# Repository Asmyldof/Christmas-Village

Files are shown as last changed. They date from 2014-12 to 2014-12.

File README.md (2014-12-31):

Christmas-Village
=================
A two cheap microcontroller project to control which of ten channels is on or off based on a true-random generator (with guaranteed no bias), while also controlling the general brightness either manually or from a light sensor.
The remainder of this ReadMe will be written as a chronological logbook, to show the speed at which the development was done.

How a missing connector inspired me to make a present in stead of buying one:
=================

Early December 2013:
-----
I glue some LED strips into the crockery Christmas Village houses my parents bought and supplied father with some pre-fab connectors and cables. That year the houses were lit at a fraction of the cost of high-watage incandescent bulbs from the supplier. (Where the LEDstrip uses less than 1/10th the power).

Early January 2014:
-----
The houses get packed into wraps and boxes.

December 19th 2014:
-----
Father WhatsApps to ask about the connector set-up, because the old one seems to have fallen out of the package at some point. We call and agree that I will get a new connector to go from one single power supply to ten houses the next week, for the main holidays (as they were busy upto Dec 22nd)

December 20th 2014:
-----
I start designing a PCB to control the houses with the shortest-path-available method, still considering reusability, and thus splitting the dimmer and the 10 channel on/off controller into two separate, relatively cheap Atmel AVRs.
The plan:
* First and foremost: Use only items from my direct stock (My stock is large, very large even, but not limitless), so it can be built the same weekend.
* Get an ATTiny10 to do the dimming and keeping an eye on the light/dark situation
* Get an ATTiny4313 to control the channels on/off, including a true-random generator without bias (more on this later)
* Add a FM noise source for very-high-speed random generation (for future plans) (see below why that's not in there anymore)

December 21st 2014 (late night):
-----
With the hardware fully designed it's time to start the etching

December 22nd 2014 (afternoon):
-----
With the hardware fully built it's time to test the noise generation from the FM antenna. The FM antenna proves to be unreliable and insensitive in the small box that has been chosen, so a lower-frequency noise source is taken: The good old Zener Diode.

December 22nd 2014 (early evening):
-----
The ATTiny10 software is ready for testing, but a paid projct takes temporary precedence.

December 22nd 2014 (late evening):
-----
The ATTiny10 is working and installed, time to go bring what is done as a present to the parental home and continue programming there later.

December 22nd/23rd 2014 (midnight and later):
-----
Development of the random control is well underway (all chips were already mounted before ATTiny10 testing started).

December 23rd 2014 (approx 5:30 AM):
-----
Random control of the houses works, time to decouple the programmer and go to bed, allowing the random behaviour as a surprise for the folks that'll wake up soon.

December 23rd (5:30 AM) through december 26th:
-----
Break (the houses are automatically dimmed by the sensor and the light sensor sucessfully influences the number of houses on - more on during the day time than during the night time - and the random behaviour works, that was the target for christmas.
(However, some work had already been done for other functionality, including patterns and EEPROM re-configurable settings, which should later be read/write-able through the serial interface (quick after thought in the hardware design).

December 27th 2014:
-----
Continuation of the development: Adding Serial interface, interleaved with shopping, cleaning and such.
(Note, however, that the hardware is not available at this point, so all code is written and tested on paper only, undoubtedly leaving bugs to be discovered when the hardware is back again for a while.)

December 28th 2014 (2:30 AM):
-----
Serial command set almost completely implemented, before the remaining command get implemented the default eeprom_ routines from AVR-GCC need to be switched over to interrupt driven and flag-bocked, or some routine splitting needs to be done to get the blocking eeprom read/writes in the non-interrupt space inside main(). Else the "ReadPattern" and "WritePattern" commands will hold up too many interrupts.

December 28th 2014 (14:00 to 16:30):
-----
A small window of hardware testing, allowing debugging of the USART code and changing some variables into GPIOR, to decrease code size. Basic USART system working, not all commands fully tested yet.

December 30th, 31st 2014 and January 1st, 2nd and 3rd 2015:
-----
More debugging to be done, before the hardware leaves, small sessions in between other activities, it's a busy week after all. Plan is to complete the USART (excepting GoToBootloader)and EEPROM interfaces and hopefully make the pattern system work completely. Once that is all completed andthere is still room enough for a two or three page fixed bootloader, at least in the 4313 setup, that will be added later (weekends during January 2015, or a little later)

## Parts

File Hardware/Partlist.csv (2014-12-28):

Partlist |  | Christmas Village Project
Part | Value | Package | Library | Position (mil) | Orientation
C1 | 2u2 | CAP-1206 | ipc-7351-capacitor | (1880 1340) | R90
C2 | 2u2 | CAP-1206 | ipc-7351-capacitor | (1880 1150) | R270
C3 | 100n | CAP-0603 | ipc-7351-capacitor | (2920 700) | R0
C4 | 100n | CAP-0603 | ipc-7351-capacitor | (3260 1390) | R90
C5 | 100n | CAP-0603 | ipc-7351-capacitor | (2260 900) | R180
C6 |  | CAP-0603 | ipc-7351-capacitor | (2340 1250) | R0
C7 |  | CAP-0603 | ipc-7351-capacitor | (2540 710) | R180
C8 | 1u | CAP-1206 | ipc-7351-capacitor | (2560 515) | R0
C9 | 1u | CAP-1206 | ipc-7351-capacitor | (2580 295) | R0
C10 | 100n | CAP-0603 | ipc-7351-capacitor | (3110 90) | R0
C11 | 100n | CAP-0603 | ipc-7351-capacitor | (1920 970) | R270
C12 | 560pF | CAP-0603 | ipc-7351-capacitor | (1910 610) | R90
C13 | 56nF | CAP-0603 | ipc-7351-capacitor | (2130 1020) | R90
CN1 | MJ-180SMT | MJ-180SMT | con-Multicomp | (80 1330) | R0
CN2-PROG | JST-6PSPI-SIDE-S6B | 6P-H | avr-6 | (3150 1420) | R180
CN3-SERIAL | JST-4PSIDE-S4B | 4P-H | Connector-2mm | (2590 1420) | R180
CN5-LEDSTRIPS | HDR_2X10_SIDE-MOUNT | 20PIN-10TOP-10BOT | con-SideHeader | (3620 1440) | R270
D1 | BP104-SMD-REV | BR104SMDREV | Vishay | (1660 380) | R270
D2 |  | MINIMELF | diode | (2080 1390) | R0
D3 | 9V1 | SOT23 | diode | (2380 390) | R180
IC1 | UA78M05DCY | SOT223 | linear | (2110 1210) | R270
IC2 | LM358D | SO08 | linear4 | (2050 800) | R0
IC3 | LM358D | SO08 | linear4 | (2870 525) | R270
IC4 | LM358D | SO08 | linear4 | (2870 205) | R90
IC5 | ATTINY-4/5/9/10 | SOT23-6 | avr-6 | (2180 1060) | R270
IC6 | TINY2313/4313 | SO20 | avr-6 | (2960 1090) | R270
POT1 |  | HDR-1x3 | con-hdrs40 | (2040 460) | R0
Q1 | Si2309CD | SOT95P280X135-3N | ipc-7351-transistor | (3590 1540) | R0
Q2 | NX7002AKW | SOT323R | ZeroCross Project | (3310 1560) | R270
Q3 | NX7002AKW | SOT323R | ZeroCross Project | (3470 1420) | R270
Q4 | NX7002AKW | SOT323R | ZeroCross Project | (3470 1330) | R270
Q5 | NX7002AKW | SOT323R | ZeroCross Project | (3470 1240) | R270
Q6 | NX7002AKW | SOT323R | ZeroCross Project | (3470 1140) | R270
Q7 | NX7002AKW | SOT323R | ZeroCross Project | (3470 1040) | R270
Q8 | NX7002AKW | SOT323R | ZeroCross Project | (3470 940) | R270
Q9 | NX7002AKW | SOT323R | ZeroCross Project | (3470 840) | R270
Q10 | NX7002AKW | SOT323R | ZeroCross Project | (3470 740) | R270
Q11 | NX7002AKW | SOT323R | ZeroCross Project | (3470 640) | R270
Q12 | NX7002AKW | SOT323R | ZeroCross Project | (3470 540) | R270
R1 | 10M | RES-0603 | ipc-7351-resistor | (1995 630) | R180
R2 | 10k | RES-0603 | ipc-7351-resistor | (1900 810) | R90
R3 | 100k | RES-0603 | ipc-7351-resistor | (2040 1010) | R180
R4 | 10k | RES-0603 | ipc-7351-resistor | (3490 1540) | R90
R5 | 10k | RES-0603 | ipc-7351-resistor | (3410 1580) | R0
R6 | 10k | RES-0603 | ipc-7351-resistor | (2680 475) | R270
R7 | 99k | RES-0603 | ipc-7351-resistor | (2660 185) | R270
R8 | 1k | RES-0603 | ipc-7351-resistor | (2640 395) | R180
R9 | 500k | RES-0603 | ipc-7351-resistor | (2730 335) | R180
R10 | 10k | RES-0603 | ipc-7351-resistor | (3080 170) | R90
R11 | 10k | RES-0603 | ipc-7351-resistor | (3080 290) | R90
R12 | 1M | RES-0603 | ipc-7351-resistor | (2380 210) | R90
SW1 | POWER | HDR-1x3 | con-hdrs40 | (2040 1550) | R0
SW2 | NIGHT-MODE | HDR-1x3 | con-hdrs40 | (2040 210) | R0
X1 | 7.3728MHz | SM49 | crystal | (2440 980) | R90

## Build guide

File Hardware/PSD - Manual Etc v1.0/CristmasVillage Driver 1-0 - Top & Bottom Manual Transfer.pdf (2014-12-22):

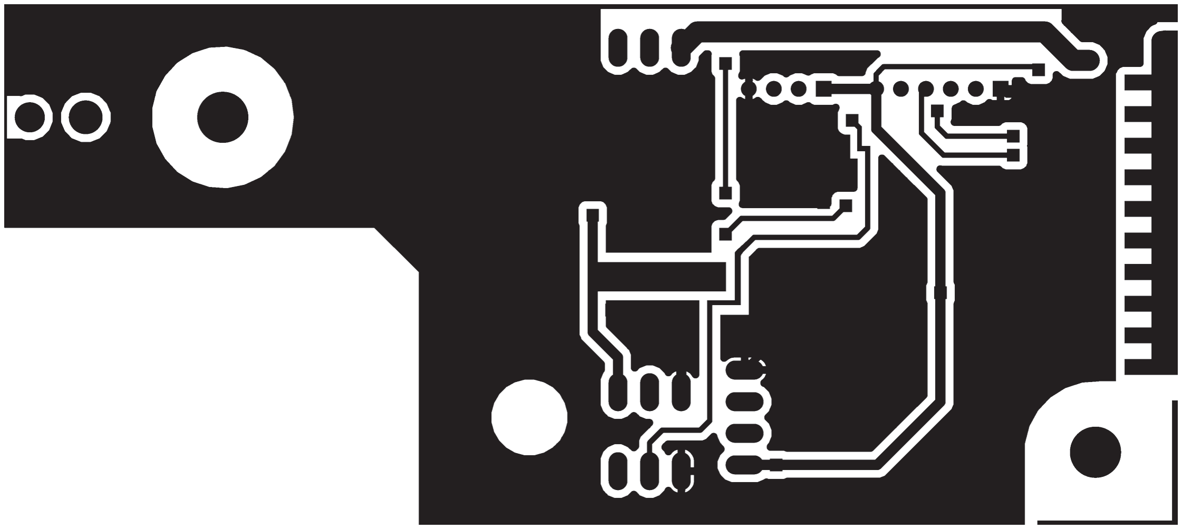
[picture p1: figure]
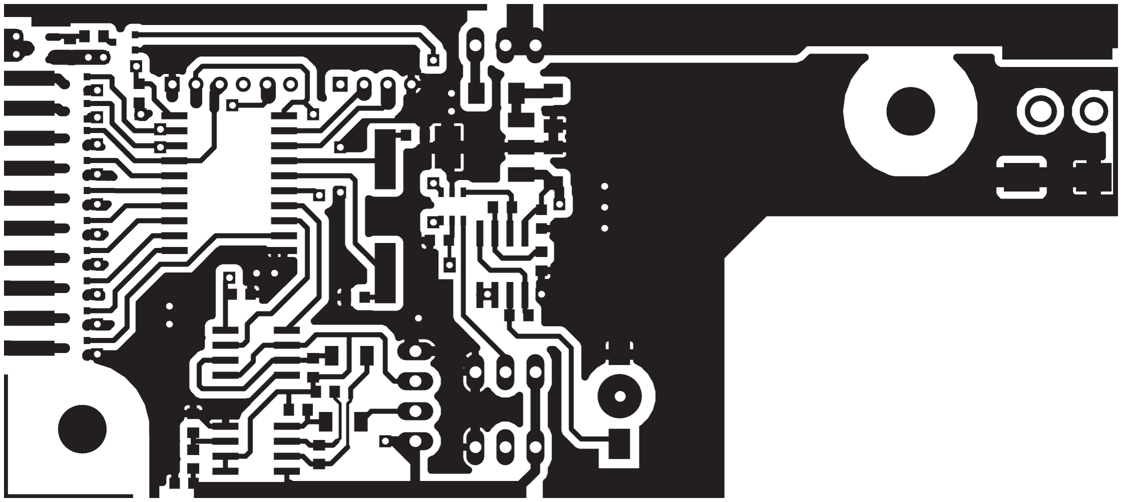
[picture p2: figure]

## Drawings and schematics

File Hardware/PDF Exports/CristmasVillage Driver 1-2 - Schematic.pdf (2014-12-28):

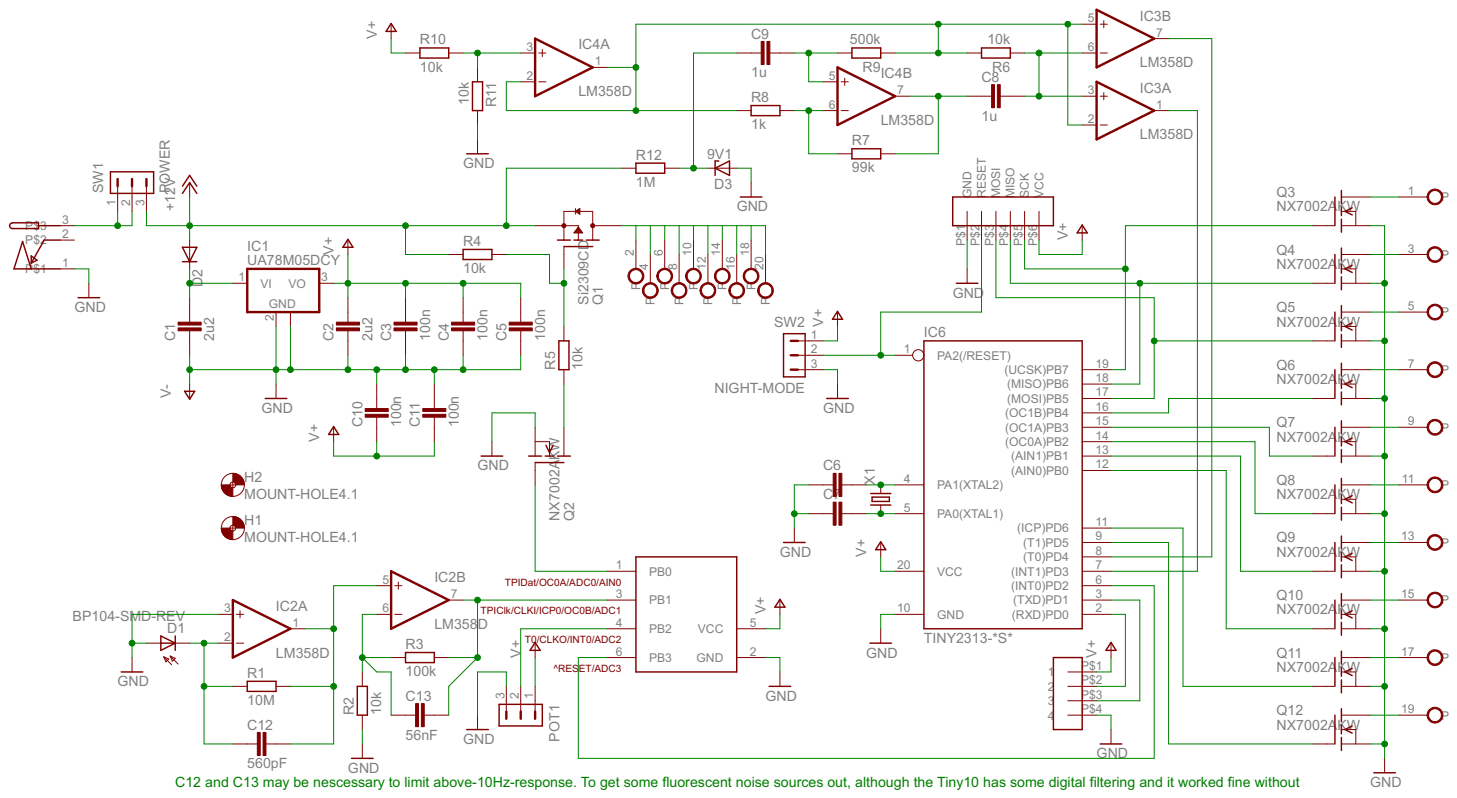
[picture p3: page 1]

14
13
12

TPIDat/OC0A/ADC0/AIN0 TPIClk/CLKI/ICP0/OC0B/ADC1 T0/CLKO/INT0/ADC2

^RESET/ADC3 C12 and C13 may be nescessary to limit above-10Hz-response. To get some fluorescent noise sources out, although the Tiny10 has some digital filtering and it worked fine without

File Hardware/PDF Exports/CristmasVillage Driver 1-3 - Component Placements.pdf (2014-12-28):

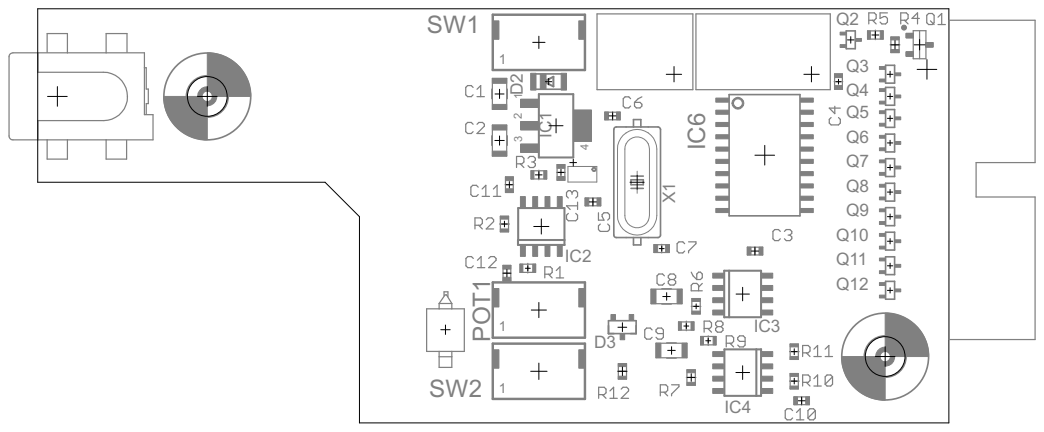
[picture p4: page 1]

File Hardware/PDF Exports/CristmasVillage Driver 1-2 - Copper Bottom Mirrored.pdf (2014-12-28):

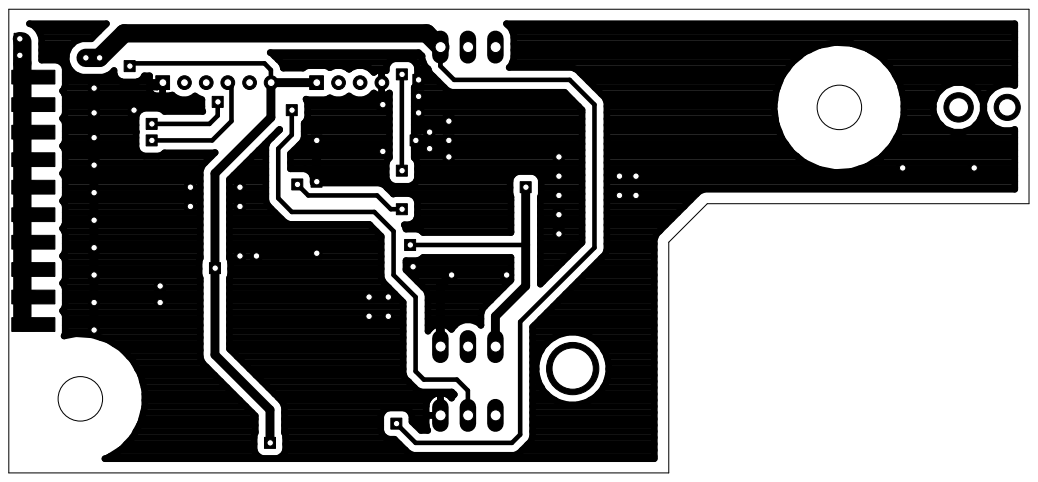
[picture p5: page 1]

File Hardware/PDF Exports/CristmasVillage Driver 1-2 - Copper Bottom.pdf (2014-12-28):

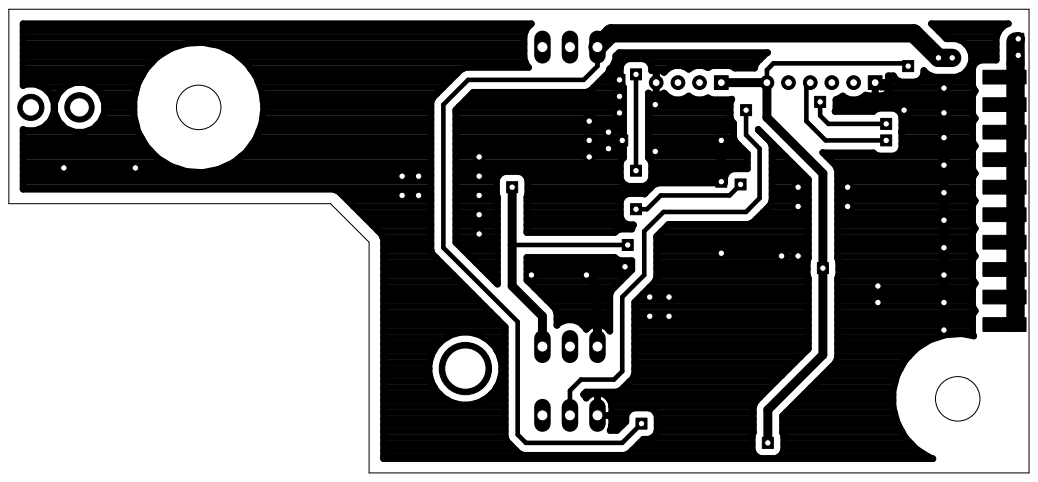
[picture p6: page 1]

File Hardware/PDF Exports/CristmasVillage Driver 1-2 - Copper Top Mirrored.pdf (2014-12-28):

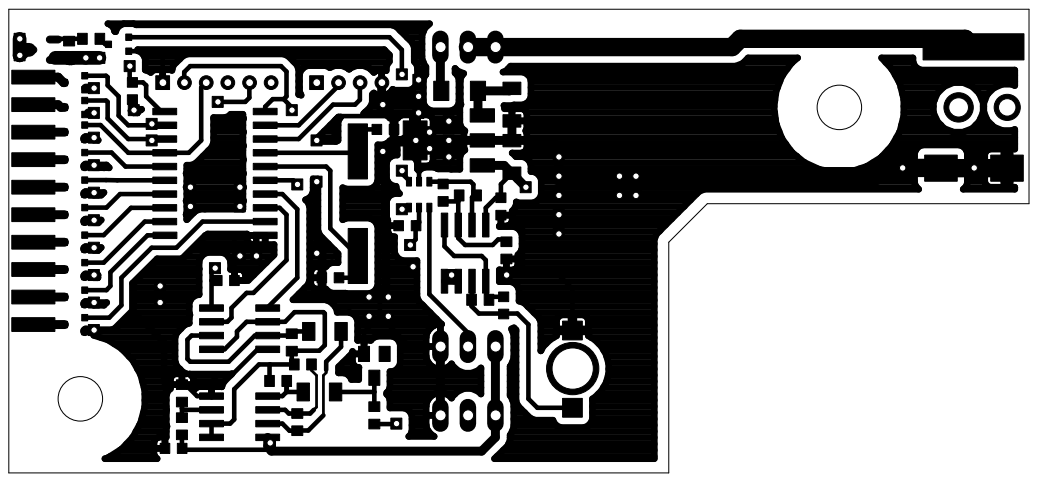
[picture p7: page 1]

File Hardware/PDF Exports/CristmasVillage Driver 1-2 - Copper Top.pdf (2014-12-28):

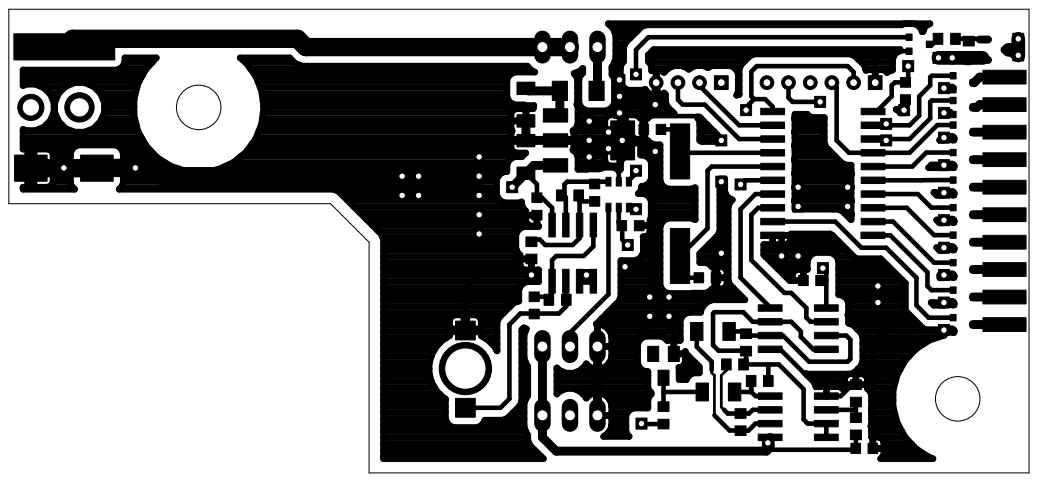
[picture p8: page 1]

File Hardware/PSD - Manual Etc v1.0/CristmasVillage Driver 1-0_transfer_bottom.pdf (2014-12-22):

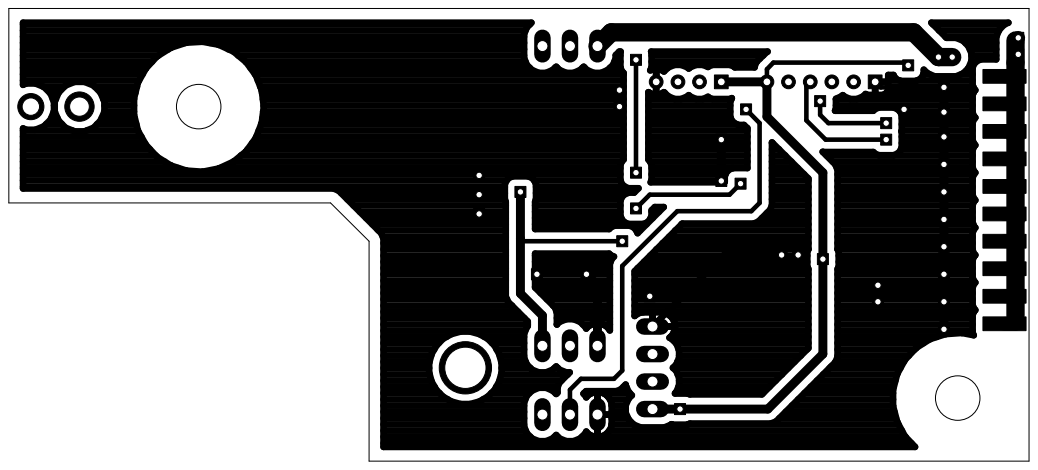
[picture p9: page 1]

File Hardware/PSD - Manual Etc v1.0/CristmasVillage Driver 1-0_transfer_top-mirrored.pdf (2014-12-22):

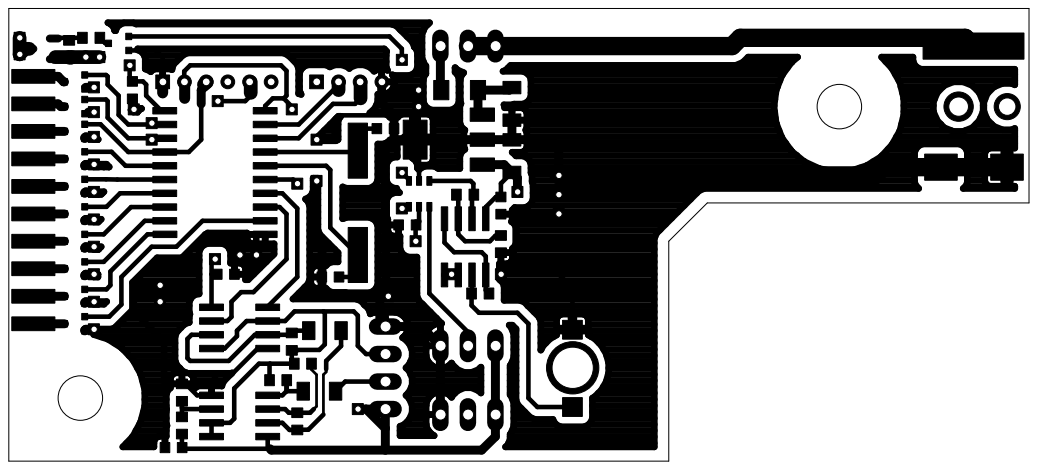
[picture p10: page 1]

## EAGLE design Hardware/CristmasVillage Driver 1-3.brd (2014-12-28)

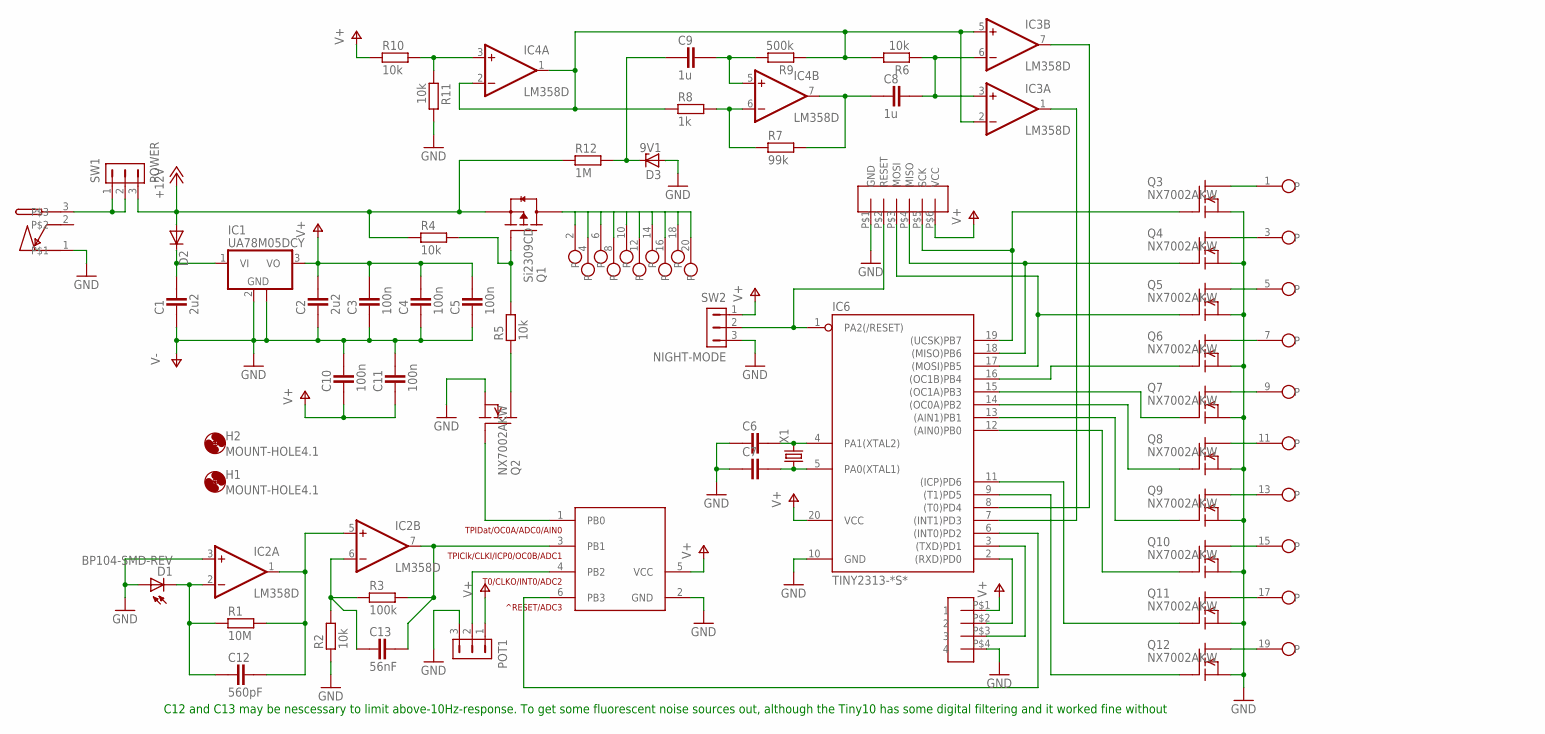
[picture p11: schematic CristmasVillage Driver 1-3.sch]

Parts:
C1, C2: 2u2; CAPC3215X168N
C3, C4, C5, C10, C11: 100n; CAPC1608X92N
C6, C7: CAPACITOR_0603; CAPC1608X92N
C8, C9: 1u; CAPC3215X168N
C12: 560pF; CAPC1608X92N
C13: 56nF; CAPC1608X92N
CN1: MJ-180SMT
CN2-PROG: JST-6PSPI-SIDE-S6B; 6P-H
CN3-SERIAL: JST-4PSIDE-S4B; 4P-H
CN5-LEDSTRIPS: HDR_2X10_SIDE-MOUNT; 20PIN-10TOP-10BOT
D1: BP104-SMD-REV; BR104SMDREV
D2: DIODE-MINIMELF; MINIMELF
D3: 9V1; SOT23
H1, H2: MOUNT-HOLE4.1; 4,1
IC1: UA78M05DCY; SOT223
IC2, IC3, IC4: LM358D; SO08
IC5: ATTINY-4/5/9/10; SOT23-6
IC6: TINY2313-*S*; SO20L$
POT1: HDR-1X3-MTE-100; MTE-100-3V
Q1: Si2309CD; SOT95P280X135-3N
Q2, Q3, Q4, Q5, Q6, Q7, Q8, Q9, Q10, Q11, Q12: NX7002AKW; SOT323R
R1: 10M; RESC1608X55N
R2, R4, R5, R6, R10, R11: 10k; RESC1608X55N
R3: 100k; RESC1608X55N
R7: 99k; RESC1608X55N
R8: 1k; RESC1608X55N
R9: 500k; RESC1608X55N
R12: 1M; RESC1608X55N
SW1: POWER; MTE-100-3V
SW2: NIGHT-MODE; MTE-100-3V
X1: CRYSTALSM49; SM49

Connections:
+12V: D2.A, Q1.2 (S), R4.1, R12.1, SW1.3
GND: C1.1, C2.1, C3.1, C4.1, C5.1, C6.1, C7.1, C10.2, C11.2, CN1.1, CN2-PROG.P$1 (GND), CN3-SERIAL.P$4 (4), D1.1 (A), D3.1 (A), IC1.2 (GND), IC1.4 (GND), IC2.3 (+IN), IC2.4 (V-), IC3.4 (V-), IC4.4 (V-), IC5.2 (GND), IC6.10 (GND), POT1.3, Q2.2 (S), Q3.2 (S), Q4.2 (S), Q5.2 (S), Q6.2 (S), Q7.2 (S), Q8.2 (S), Q9.2 (S), Q10.2 (S), Q11.2 (S), Q12.2 (S), R2.1, R11.2, SW2.3
HALF-VCC: IC3.2 (-IN), IC3.5 (+IN), IC4.1 (OUT), IC4.2 (-IN), R6.2, R8.1, R9.1
MISO: CN2-PROG.P$4 (MISO), IC6.18 ((MISO)PB6), Q4.1 (G)
MOSI: CN2-PROG.P$3 (MOSI), IC6.17 ((MOSI)PB5), Q5.1 (G)
unnamed: C1.2, D2.C, IC1.1 (VI)
unnamed: C12.1, D1.2 (C), IC2.2 (-IN), R1.1
unnamed: C12.2, IC2.1 (OUT), IC2.5 (+IN), R1.2
unnamed: C13.1, IC2.6 (-IN), R2.2, R3.1
unnamed: C13.2, IC2.7 (OUT), IC5.3 (PB1), R3.2
unnamed: IC6.9 ((T1)PD5), Q12.1 (G)
unnamed: IC5.1 (PB0), Q2.1 (G)
unnamed: IC6.11 ((ICP)PD6), Q11.1 (G)
unnamed: C6.2, IC6.4 (PA1(XTAL2)), X1.2
unnamed: C7.2, IC6.5 (PA0(XTAL1)), X1.1
unnamed: IC6.12 ((AIN0)PB0), Q10.1 (G)
unnamed: IC6.13 ((AIN1)PB1), Q9.1 (G)
unnamed: IC6.14 ((OC0A)PB2), Q8.1 (G)
unnamed: IC6.15 ((OC1A)PB3), Q7.1 (G)
unnamed: CN2-PROG.P$2 (RESET), IC6.1 (PA2(/RESET)), SW2.2
unnamed: IC5.6 (PB3), IC6.6 ((INT0)PD2)
unnamed: IC5.4 (PB2), POT1.2
unnamed: IC6.16 ((OC1B)PB4), Q6.1 (G)
unnamed: CN5-LEDSTRIPS.1, Q3.3 (D)
unnamed: CN1.3, SW1.1, SW1.2
unnamed: CN5-LEDSTRIPS.3, Q4.3 (D)
unnamed: CN5-LEDSTRIPS.5, Q5.3 (D)
unnamed: CN5-LEDSTRIPS.7, Q6.3 (D)
unnamed: CN5-LEDSTRIPS.9, Q7.3 (D)
unnamed: CN5-LEDSTRIPS.11, Q8.3 (D)
unnamed: CN5-LEDSTRIPS.13, Q9.3 (D)
unnamed: CN5-LEDSTRIPS.15, Q10.3 (D)
unnamed: CN5-LEDSTRIPS.17, Q11.3 (D)
unnamed: CN5-LEDSTRIPS.19, Q12.3 (D)
unnamed: CN5-LEDSTRIPS.2, CN5-LEDSTRIPS.4, CN5-LEDSTRIPS.6, CN5-LEDSTRIPS.8, CN5-LEDSTRIPS.10, CN5-LEDSTRIPS.12, CN5-LEDSTRIPS.14, CN5-LEDSTRIPS.16, CN5-LEDSTRIPS.18, CN5-LEDSTRIPS.20, Q1.3 (D)
unnamed: Q1.1 (G), R4.2, R5.2
unnamed: Q2.3 (D), R5.1
unnamed: IC3.1 (OUT), IC6.7 ((INT1)PD3)
unnamed: IC3.7 (OUT), IC6.8 ((T0)PD4)
unnamed: C8.2, IC3.3 (+IN), IC3.6 (-IN), R6.1
unnamed: IC4.3 (+IN), R10.2, R11.1
unnamed: C8.1, IC4.7 (OUT), R7.2
unnamed: IC4.6 (-IN), R7.1, R8.2
unnamed: C9.2, IC4.5 (+IN), R9.2
unnamed: C9.1, D3.3 (C), R12.2
RX: CN3-SERIAL.P$2 (2), IC6.2 ((RXD)PD0)
SCK: CN2-PROG.P$5 (SCK), IC6.19 ((UCSK)PB7), Q3.1 (G)
TX: CN3-SERIAL.P$3 (3), IC6.3 ((TXD)PD1)
V+: C2.2, C3.2, C4.2, C5.2, C10.1, C11.1, CN2-PROG.P$6 (VCC), CN3-SERIAL.P$1 (1), IC1.3 (VO), IC2.8 (V+), IC3.8 (V+), IC4.8 (V+), IC5.5 (VCC), IC6.20 (VCC), POT1.1, R10.1, SW2.1

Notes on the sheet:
C12 and C13 may be nescessary to limit above-10Hz-response. To get some fluorescent noise sources out, although the Tiny10 has some digital filtering and it worked fine without

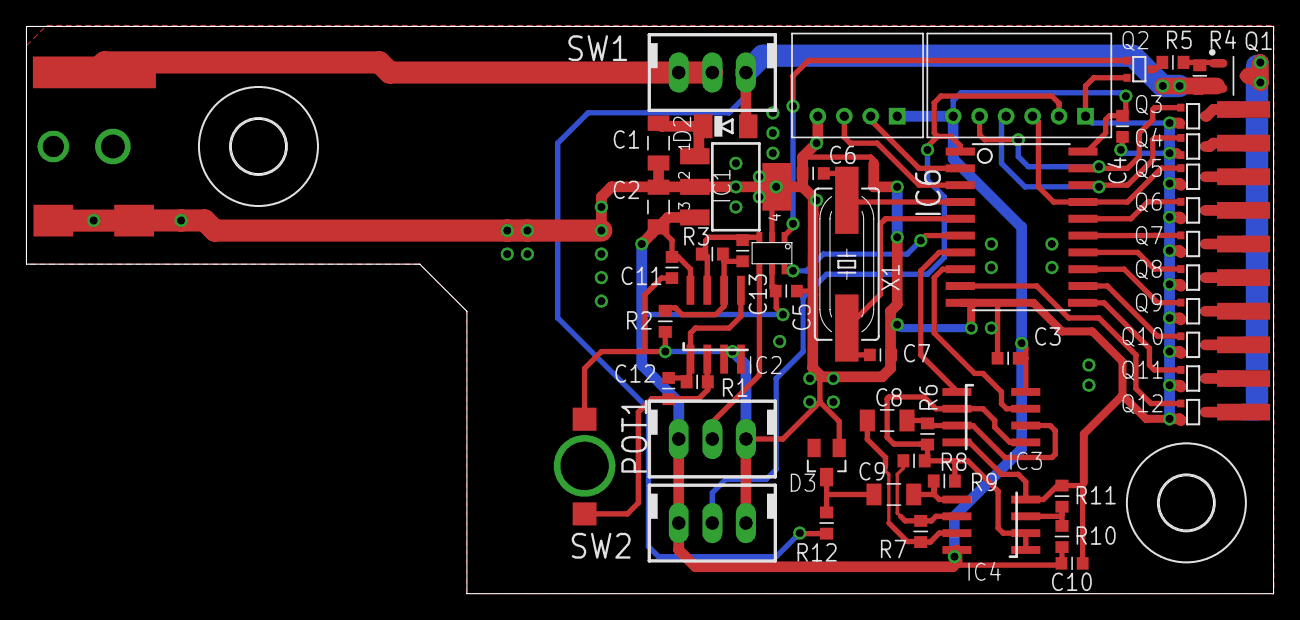
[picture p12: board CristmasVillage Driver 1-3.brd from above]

Board: 2 copper layers, 94.2 x 42.9 mm, 56 parts (0 on the bottom side), 49 nets.

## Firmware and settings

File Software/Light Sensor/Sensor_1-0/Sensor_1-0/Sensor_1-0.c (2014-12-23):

/*
 * Sensor_1_0.c
 *
 * Created: 22-12-2014 13:36:16
 *  Author: Robert
 */ 

#include <avr/io.h>
#include <avr/interrupt.h>


/* internal functions: */
inline static uint8_t	AddValueToStack(uint8_t Value);
inline static void StartADC();

/*
 * In the hardware in this project the values are as follows:
 * Completely dark room: 87mV   (4.4bit)
 * Absolute minimum value: 81mV   (4.1bit)
 * Gloomy room: 140mV   (7.1 bit)
 * Low lighting: 400mV    (20.4 bit)
 * Well lit room: 780mV    (39.8 bit)
 * Brightly lit room: 950mV    (48.4 bit)
 * Sunny room: 1905mV    (97.2 bit)
 */

#define		SENSOR_ADCVAL_DARK				7  // At which value will it start triggering night mode
#define		SENSOR_ADCVAL_MAXIMUM			68  // At which value will it go to maximum brightness
#define		SENSOR_ADCVAL_MINIMUM			5  // At which value will it go to minimum brightness

#define		PWM_OUT_AUTO_MINIMUM			128 //AUTO Mode minimum output PWM value
#define		PWM_OUT_AUTO_MAXIMUM			255 //AUTO Mode maximum output PWM value

// the system:
//  temp = [sensor value] - [minimum sensor value]
//  if(temp < 0) temp = 0;
//  temp = temp << [shift up by]
//  temp = temp + [pwm out minimum]
//  if( temp > [pwm out maximum] ) temp = [pwm out maximum];
//  <pwm output> = temp
#define		PWM_SENSOR_SHIFTUP_BY			1	

#define		POTENTIOMETER_DISABLE_ALL_AUTO	250		// above this level the sensor does nothing
#define		POTENTIOMETER_MANUALDIM_MAX		192		// above this level the lights are full on
#define		POTENTIOMETER_MANUALDIM_MIN		64		// 
#define		POTENTIOMETER_AUTO_SEPERATION	5		// the split value in the AUTO range

#define		PWM_OUT_SHIFTUP_BY				1


#define		ADC_SENSOR_STACKSIZE			15

#define		ADC_PRESCALER					3 // Default 1MHz gives 125kHz ADC clock.
/*
ADC Clock should be between 50kHz and 200kHz for best operation
 0 - CkIO / 2
 1 - CkIO / 2
 2 - CkIO / 4
 3 - CkIO / 8
 4 - CkIO / 16
 5 - CkIO / 32
 6 - CkIO / 64
 7 - CkIO / 128
 ** Any higher numbers will be masked down to the above series (i.e. 8 = 0, 9 = 1, etc) **
*/

#define		WATCHDOG_PRESACLE			1
/*
The ADC is started by the watchdog time-out, higher frequency gives better potentiometer response
but lower levels of filtering out noise on the sensor:
0 - 16ms
1 - 32ms
2 - 64ms
3 - 0.125s
4 - 0.25s
5 - 0.5s
6 - 1s
7 - 2s
32 - 4s
33 - 8s

Value is masked, so mistakes are protected from causing unpredictable behaviour, beyond
a strange, unexpected time-out
*/




/*
 * In the hardware setup of this project:
 * LED PWM Output = PB0 / OCR0A
 * NIGHTMODE Pin = PB3 / Reset
 * Sensor = PB1 / ADC1
 * Poti = PB2 / ADC2
 */
#define		OCR0_OUTPUTREGISTER				OCR0AL
#define		TCCR0A_VALUE					0b10000001
#define		TCCR0B_VALUE					0b00001001 // Set to prescaler 1, fast PWM 8bit


#define		PORTB_OUT_PWMPIN				(1 << PORTB0)
#define		PORTB_OUT_NIGHTMODE				(1 << PORTB3)
#define		PINB_IN_POTENTIOMETER			(1 << PINB2)
#define		PINB_IN_SENSOR					(1 << PINB1)
#define		ADC_DIDR_POTENTIOMETER			(1 << ADC2D)
#define		ADC_DIDR_SENSOR					(1 << ADC1D)
#define		ADC_ADMUX_SENSOR				0x01
#define		ADC_ADMUX_POTENTIOMETER			0x02



uint8_t		SensorStack[ADC_SENSOR_STACKSIZE];
uint8_t		PotentiometerVal;


/* automated define, no touhy! */
#if (WATCHDOG_PRESACLE > 33)
#warning 'Watchdog prescaler set to a bad value (too high), setting to 8seconds'
	#undef WATCHDOG_PRESACLE
	#define WATCHDOG_PRESACLE 33
#endif


int main(void)
{
    // during development nightmode output is disabled, to avoid triggering reset:
	// TODO: uncomment when reset disable will be set:
	DDRB = (PORTB_OUT_PWMPIN | PORTB_OUT_NIGHTMODE);
	PORTB = 0x00;
	
	// Disable the input logic on the ADC channels:
	DIDR0 = (ADC_DIDR_POTENTIOMETER | ADC_DIDR_SENSOR);
	
	ADMUX = ADC_ADMUX_POTENTIOMETER;
	// ADCSRA is set in StartConversion()
	
	// enable Watchdog interrupt and mask the prescaler:
	WDTCSR = (1<<WDIE)|(WATCHDOG_PRESACLE & 0x27);
	
	OCR0AH = 0;
	OCR0AL = 0;
	OCR0BH = 0;
	OCR0BL = 0;
	
	TCCR0A = TCCR0A_VALUE;
	TCCR0B = TCCR0B_VALUE;
	
	//enable all interrupts:
	sei();
	
	while(1)
    {
        //TODO:: Please write your application code 
    }
}


ISR(WDT_vect)
{
	WDTCSR |= (1<<WDIE);
	StartADC();
}


ISR(ADC_vect)
{
	uint8_t		temp;
	uint8_t		avg;

	temp = ADCL;
	
	if( ADMUX == ADC_ADMUX_SENSOR )
	{
		if( temp < SENSOR_ADCVAL_MINIMUM )
			temp = SENSOR_ADCVAL_MINIMUM;
		
		avg = AddValueToStack(temp);
		temp = avg;
		
		if( temp > SENSOR_ADCVAL_MAXIMUM )
			temp = SENSOR_ADCVAL_MAXIMUM;
		
		temp -= SENSOR_ADCVAL_MINIMUM;

		temp = temp << PWM_SENSOR_SHIFTUP_BY;
		
		temp += PWM_OUT_AUTO_MINIMUM;

		if( temp > PWM_OUT_AUTO_MAXIMUM )
			temp = PWM_OUT_AUTO_MAXIMUM;
		
		if( PotentiometerVal < POTENTIOMETER_MANUALDIM_MIN )
		{
			OCR0_OUTPUTREGISTER = temp;
		
			if( PotentiometerVal > POTENTIOMETER_AUTO_SEPERATION )
			{
				if( avg < SENSOR_ADCVAL_DARK )
				{
					PORTB |= PORTB_OUT_NIGHTMODE;
				}
				else
				{
					PORTB &= ~PORTB_OUT_NIGHTMODE;
				}
			}
			else
			{
				PORTB &= ~PORTB_OUT_NIGHTMODE;
			}
		}
		else if( PotentiometerVal < POTENTIOMETER_DISABLE_ALL_AUTO )
		{
			if( avg < SENSOR_ADCVAL_DARK )
			{
				PORTB |= PORTB_OUT_NIGHTMODE;
			}
			else
			{
				PORTB &= ~PORTB_OUT_NIGHTMODE;
			}
		}
		else
		{
			PORTB &= ~PORTB_OUT_NIGHTMODE;
		}
	
		ADMUX = ADC_ADMUX_POTENTIOMETER;
	}
	else
	{
		PotentiometerVal = temp;
		
		if( PotentiometerVal < POTENTIOMETER_MANUALDIM_MAX )
		{
			if( PotentiometerVal >= POTENTIOMETER_MANUALDIM_MIN )
			{ /* we are manually dimming */
				temp = PotentiometerVal - POTENTIOMETER_MANUALDIM_MIN;
				temp = temp << PWM_OUT_SHIFTUP_BY;
				OCR0_OUTPUTREGISTER = temp;
			}
		}
		else
		{
			OCR0_OUTPUTREGISTER = 255;
		}
		
		ADMUX = ADC_ADMUX_SENSOR;
	}
}


/*
 *  Puts a value onto the sensor stack, calculates the stack average and returns it.
 */
inline static uint8_t	AddValueToStack(uint8_t Value) 
{
	uint16_t	temp = Value;
	
	for( uint8_t itt = 0; itt < ADC_SENSOR_STACKSIZE; itt++ )
	{
		temp += SensorStack[itt];
		if( itt == (ADC_SENSOR_STACKSIZE - 1) )
			SensorStack[itt] = Value;
		else
			SensorStack[itt] = SensorStack[itt + 1];			
	}
	
	return (uint8_t) (temp / (ADC_SENSOR_STACKSIZE+1));
}

/*
 * Starts the ADC for a one time run
 */
inline static void StartADC()
{
	ADCSRA = ((1<<ADEN)|(1<<ADSC)|(1<<ADIE)|(ADC_PRESCALER & 0x07));
}

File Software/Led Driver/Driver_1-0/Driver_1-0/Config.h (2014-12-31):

/*

*/

// Project Hardware set up as follows:
// PORTB = output 1 through 8
// PORTD6 = output 9
// PORTD5 = output 10
// PORTD4 = Random Bitstream Positive
// PORTD3 / INT1 = Random Bitstream Negative
// PORTD2 / INT0 = Night Mode input
// PORTD0 / RXD = Serial interface
// PORTD1 / TXD = Serial interface
// PORTA2 / RESET = Random / Pattern select
//
// Crystal = 7.3728 MHz
// Serial Baud = 115.2k
// U2X = 0
// UBRR = 3
// Set to: 1 start bit, 2 stop bits, odd parity, 8 data bits

#ifndef __LED_DRIVER_CONFIG_H__
#define __LED_DRIVER_CONFIG_H__

//#define		DEBUGGING_TIMESCALE // if defined, the WDT times out about 60 times as often (16ms), to turn a minute into 2 seconds.
//#define		RESET_IS_DISABLED // Define if the reset is going to be disabled
#define		STORE_FLAGBYTES_IN_GPIOR // Store the flag bytes in General Purpose Registers, for efficiency
#define		STORE_PACKETOUTCOUNT_INGPIOR2 // Store the last random in GPIOR2, for efficiency (250 byte code size reduction)

#define		VERSION_MAJOR						1
#define		VERSION_MINOR						2
#define		VERSION_RELEASE						16

#define		PROJECT_SIGNATURE_HIGH				0x80 // MSB high, publicly available project 
//   (means care must be taken with a potential future Asmyldof Suite when a project is "compiled at home")
//   Remaining bits signify stuff that is not decided yet, possibly internal differentiations between project types
//   for non-open-source (MSB zero) embedded devices.

#define		PROJECT_SIGNATURE_MID				0x00 // Mid & Low together make an incremental 16bit project number for each MSB category
#define		PROJECT_SIGNATURE_LOW				0x03



#define		MAXIMUM_PATTERN_SIZE			(E2END - 16)  // Take into account the available EEPROM, minus all other configuration bytes (version 1.0 / 1.1: 10 bytes)
#define		SERIAL_BUFFER_SIZE				16  // Size of serial port communication buffers
#define		RANDOM_STACK_SIZE				16  // can be anything between 2 and whatever still fits the memory
#define		EEPROM_BLOCK_WRITE_BUFFER		16  // Minimum 16, maximum, whatever fits.

#define		EEPROM_PATTERN_HOUSENUMMASK		0xF0
#define		EEPROM_PATTERN_DELAYTIMMASK		0x0F

// Location of the mode pin (project hardware: PortA2 / Reset):
#define		PORTIN_MODE						PINA
#define		PIN_MODE						(1 << PINA2)
// if MODE pin = high random mode runs, if MODE pin = low it runs in pattern mode


#define		PORTIN_NIGHTMODE				PIND
#define		PIN_NIGHTMODE					(1<<PIND2)


// LED outputs:
#define		PORTOUT_HOUSE0					PORTB
#define		PORTIN_HOUSE0					PINB
#define		PIN_HOUSE0						(1<<PORTB7)

#define		PORTOUT_HOUSE1					PORTB
#define		PORTIN_HOUSE1					PINB
#define		PIN_HOUSE1						(1<<PORTB6)

#define		PORTOUT_HOUSE2					PORTB
#define		PORTIN_HOUSE2					PINB
#define		PIN_HOUSE2						(1<<PORTB5)

#define		PORTOUT_HOUSE3					PORTB
#define		PORTIN_HOUSE3					PINB
#define		PIN_HOUSE3						(1<<PORTB4)

#define		PORTOUT_HOUSE4					PORTB
#define		PORTIN_HOUSE4					PINB
#define		PIN_HOUSE4						(1<<PORTB3)

#define		PORTOUT_HOUSE5					PORTB
#define		PORTIN_HOUSE5					PINB
#define		PIN_HOUSE5						(1<<PORTB2)

#define		PORTOUT_HOUSE6					PORTB
#define		PORTIN_HOUSE6					PINB
#define		PIN_HOUSE6						(1<<PORTB1)

#define		PORTOUT_HOUSE7					PORTB
#define		PORTIN_HOUSE7					PINB
#define		PIN_HOUSE7						(1<<PORTB0)

#define		PORTOUT_HOUSE8					PORTD
#define		PORTIN_HOUSE8					PIND
#define		PIN_HOUSE8						(1<<PORTD6)

#define		PORTOUT_HOUSE9					PORTD
#define		PORTIN_HOUSE9					PIND
#define		PIN_HOUSE9						(1<<PORTD5)


#define		PORTIN_RANDOM_POS				PIND
#define		PIN_RANDOM_POS					(1<<PIND4)
#define		PORTIN_RANDOM_NEG				PIND
#define		PIN_RANDOM_NEG					(1<<PIND3)


// Start-up values for the port and DDR registers:
#define		DDRA_STARTUP					0x00
#define		DDRB_STARTUP					0xFF
#define		DDRD_STARTUP					0x60 | (1 << PORTD1) // PORTD1 = TXD pin, make high too.

#define		PORTA_STARTUP					0x00 | (1<<PORTA2) // Set weak pull-up active on the reset
// Port definitions for all pins on:
#define		PORTB_STARTUP_ALL_ON			0xFF
#define		PORTD_STARTUP_ALL_ON			0x60

#ifdef	DEBUGGING_TIMESCALE
#define		WDTCSR_STARTUP				(1<<WDIE) // Prescaled to about 16 mili second interval, enable the watchdog interrupt
#else	// DEBUGGING_TIMESCALE
#define		WDTCSR_STARTUP				( (1<<WDIE)|(1<<WDP2) ) // Prescaled to about 1/4 second interval, enable the watchdog interrupt
#endif	// DEBUGGING_TIMESCALE

#define		TCCR_RANDOM_A_STARTUP					(1<<WGM01) // Select CTC Mode on OCR0A
#define		TCCR_RANDOM_B_STARTUP					( (1<<CS01)|(1<<CS00) ) // Prascale by 64
#define		OCR_RANDOM_A_STARTUP					11 // Overflow at 115 to sample at about 1kHz (about 125 truly random numbers per second)

#define		TIMSK_STARTUP					(1<<OCIE0A)
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

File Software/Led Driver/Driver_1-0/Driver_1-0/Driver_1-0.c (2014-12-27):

/*
 * Driver_1_0.c
 *
 * Created: 22-12-2014 20:54:38
 *  Author: Robert
 */ 
// PORTB = output 1 through 8
// PORTD6 = output 9
// PORTD5 = output 10
// PORTD4 = Random Bitstream Positive
// PORTD3 / INT1 = Random Bitstream Negative
// PORTD2 / INT0 = Night Mode input
// PORTD0 / RXD = Serial interface
// PORTD1 / TXD = Serial interface
// PORTA2 / RESET = Random / Pattern select
// 
// Crystal = 7.3728 MHz
// Serial Baud = 115.2k
// U2X = 0
// UBRR = 3

#include <avr/io.h>
#include <avr/interrupt.h>
#include <avr/eeprom.h>
#include "USART-Commands.h"

//#define		DEBUGGING_TIMESCALE // if defined, the WDT times out about 60 times as often (16ms), to turn a minute into 2 seconds.
// #define	RESET_IS_DISABLED // Define if the reset is going to be disabled

#define		VERSION_MAJOR						1
#define		VERSION_MINOR						0
#define		VERSION_RELEASE						6

// Default EEPROM Preloads:
#define		DEF_DAY_TIME_TARGET_NUMBER_HOUSES	8 // during the day the device will slowly increase to this number
#define		DEF_NIGHT_TIME_TARGET_NUMBER_HOUSES	3 // at night time mode the device will slowly decrease to this number
#define		DEF_MINIMUM_NUMBER_OF_HOUSES		0 // used when trying to set a number of houses with serial interface
#define		DEF_MAIN_STEPDELAY					25 // number of 1s WDT interrupts per step in pattern
#define		DEF_RANDOM_STEP_DELAY				50 // number of 1s WDT interrupts per step in random
#define		DEF_NIGHTTIME_TICKS					80 // number of RandomSteps between target number houses decrements
#define		DEF_STARTUP_DELAY					240 // 240 quarter second startup: 1 minute

#define		DEF_PATTERN_STEP_COUNT				90
// in the pattern, the first nibble is the house to toggle, the second nibble is the post-delay steps untill the
//   next action is taken.
#define		DEF_PATTERN							{	0x11, 0xAF, 0x06, 0xA3, 0x21, 0x02, 0x95, 0x11, 0x50, 0x13, \
													0x45, 0x1B, 0x23, 0x54, 0xA2, 0x15, 0x86, 0x27, 0x19, 0x28, \
													0x23, 0x71, 0x44, 0x26, 0x63, 0x66, 0xA7, 0x36, 0x98, 0x7F, \
													0x87, 0x05, 0x38, 0x97, 0x77, 0x83, 0x18, 0x43, 0x56, 0x5C, \
													0x43, 0x24, 0x72, 0x4A, 0x23, 0x49, 0x39, 0x50, 0x42, 0x96, \
													0x51, 0x59, 0x94, 0x63, 0x15, 0x50, 0x81, 0x67, 0x74, 0x22, \
													0x70, 0x88, 0x3C, 0x72, 0x83, 0x9A, 0x02, 0x72, 0x39, 0x47, \
													0x93, 0xA1, 0xA4, 0x38, 0x92, 0xAE, 0x13, 0x8D, 0x24, 0x90, \
													0x17, 0x12, 0x27, 0x16, 0x31, 0x24, 0x34, 0x95, 0xA3, 0x62, \
													}

#define		MAXIMUM_PATTERN_SIZE			95  // Take into account the stack and 8 bytes of RAM used in general
#define		SERIAL_BUFFER_SIZE				16  // Size of serial port communication buffers

#define		EEPROM_PATTERN_HOUSENUMMASK		0xF0
#define		EEPROM_PATTERN_DELAYTIMMASK		0x0F

// Location of the mode pin (project hardware: PortA2 / Reset):
#define		PORTIN_MODE						PINA
#define		PIN_MODE						(1 << PINA2)
// if MODE pin = high random mode runs, if MODE pin = low it runs in pattern mode


#define		PORTIN_NIGHTMODE				PIND
#define		PIN_NIGHTMODE					(1<<PIND2)


// LED outputs:
#define		PORTOUT_HOUSE0					PORTB
#define		PORTIN_HOUSE0					PINB
#define		PIN_HOUSE0						(1<<PORTB7)

#define		PORTOUT_HOUSE1					PORTB
#define		PORTIN_HOUSE1					PINB
#define		PIN_HOUSE1						(1<<PORTB6)

#define		PORTOUT_HOUSE2					PORTB
#define		PORTIN_HOUSE2					PINB
#define		PIN_HOUSE2						(1<<PORTB5)

#define		PORTOUT_HOUSE3					PORTB
#define		PORTIN_HOUSE3					PINB
#define		PIN_HOUSE3						(1<<PORTB4)

#define		PORTOUT_HOUSE4					PORTB
#define		PORTIN_HOUSE4					PINB
#define		PIN_HOUSE4						(1<<PORTB3)

#define		PORTOUT_HOUSE5					PORTB
#define		PORTIN_HOUSE5					PINB
#define		PIN_HOUSE5						(1<<PORTB2)

#define		PORTOUT_HOUSE6					PORTB
#define		PORTIN_HOUSE6					PINB
#define		PIN_HOUSE6						(1<<PORTB1)

#define		PORTOUT_HOUSE7					PORTB
#define		PORTIN_HOUSE7					PINB
#define		PIN_HOUSE7						(1<<PORTB0)

#define		PORTOUT_HOUSE8					PORTD
#define		PORTIN_HOUSE8					PIND
#define		PIN_HOUSE8						(1<<PORTD6)

#define		PORTOUT_HOUSE9					PORTD
#define		PORTIN_HOUSE9					PIND
#define		PIN_HOUSE9						(1<<PORTD5)


#define		PORTIN_RANDOM_POS				PIND
#define		PIN_RANDOM_POS					(1<<PIND4)
#define		PORTIN_RANDOM_NEG				PIND
#define		PIN_RANDOM_NEG					(1<<PIND3)


// Start-up values for the port and DDR registers:
#define		DDRA_STARTUP					0x00
#define		DDRB_STARTUP					0xFF
#define		DDRD_STARTUP					0x60 | (1 << PORTD1) // PORTD1 = TXD pin, make high too.

#define		PORTA_STARTUP					0x00
#define		PORTB_STARTUP					0xFF
#define		PORTD_STARTUP					0x60

#ifdef	DEBUGGING_TIMESCALE
	#define		WDTCSR_STARTUP				(1<<WDIE) // Prescaled to about 16 mili second interval, enable the watchdog interrupt
#else	// DEBUGGING_TIMESCALE
	#define		WDTCSR_STARTUP				(1<<WDIE)|(1<<WDP2) // Prescaled to about 1/4 second interval, enable the watchdog interrupt
#endif	// DEBUGGING_TIMESCALE

#define		TCCR0A_STARTUP					(1<<WGM01) // Select CTC Mode on OCR0A
#define		TCCR0B_STARTUP					(1<<CS01)|(1<<CS00) // Prascale by 64
#define		OCR0A_STARTUP					11 // Overflow at 115 to sample at about 1kHz (about 125 truly random numbers per second)

#define		TIMSK_STARTUP					(1<<OCIE0A)


/*
 * Internal Helper Functions:
 */
inline static void SetHouseOn(uint8_t HouseNumber);
inline static void SetHouseOff(uint8_t HouseNumber);
inline static void ProcessRandomHouseToggle();
inline static void ProcessPatternStep();


uint8_t EEMEM	EE_TargetNumberHousesDayTime = DEF_DAY_TIME_TARGET_NUMBER_HOUSES;
uint8_t EEMEM	EE_MinimumNumberHouses = DEF_MINIMUM_NUMBER_OF_HOUSES;
uint8_t EEMEM	EE_TargetNumberHousesNightTime = DEF_NIGHT_TIME_TARGET_NUMBER_HOUSES;
uint8_t EEMEM	EE_PatternStepCount = DEF_PATTERN_STEP_COUNT;
uint8_t	EEMEM	EE_MainStepDelay = DEF_MAIN_STEPDELAY;
uint8_t EEMEM	EE_RandomStepDelay = DEF_RANDOM_STEP_DELAY;
uint8_t EEMEM	EE_PatternData[MAXIMUM_PATTERN_SIZE] = DEF_PATTERN;
uint8_t	EEMEM	EE_PostDelayTicksNightTime = DEF_NIGHTTIME_TICKS;
uint8_t EEMEM	EE_StartupDelay = DEF_STARTUP_DELAY;

uint8_t	WDTPostDecrement; // Decrementer for the WDT interrupt
uint8_t LastRandom; // Random number, updated at a constant interval (standard config about 125 unique random bytes per second)
uint8_t	TempRandom; // Temporary memory for creating the random number
uint8_t	RandomBitCount; // Counter for the random generator
uint8_t	CurrentTargetHouses; // Number of houses we want turned on at present
uint8_t	NightTimeDecreaseDecounter; // Decrementer for the slow increase or decrease of target house numbers

uint8_t	CurrentPatternIndex; // pointer byte to the index of the pattern data
uint8_t SerialByteCount; //
uint8_t SerialPacketPayloadLength; // 
uint8_t SerialInBuffer[SERIAL_BUFFER_SIZE]; // Serial port read (RX) buffer
uint8_t SerialOutBuffer[SERIAL_BUFFER_SIZE]; // Serial port send (TX) buffer
uint8_t SerialInBuf_Index; // 
uint8_t SerialOutBuf_Index; // 

uint8_t	MainFlags; // Byte of processing flags

#define		FLAG_PROCESS_RANDOMHOUSE		0x01
#define		FLAG_PROCESS_PATTERNSTEP		0x02
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

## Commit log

2014-12-21 First part of the Schematic drawn
    [CristmasVillage Driver 1-0.sch]
2014-12-21 Decided on adding light sensor
    [CristmasVillage Driver 1-0.sch]
2014-12-21 Decided on power connector, hooked up dimming, added Tiny2313/4313
    [CristmasVillage Driver 1-0.sch]
2014-12-21 schematic complete, transferred to board
    [CristmasVillage Driver 1-0.brd, CristmasVillage Driver 1-0.sch]
2014-12-22 Almost entire LED controller routed, including random antenna experiment
    [CristmasVillage Driver 1-0.brd]
2014-12-22 Decided on a plastic box from old stock and adjusted board size + some more routing
    [CristmasVillage Driver 1-0.brd]
2014-12-22 Hardware design all done, exported for manual etching.
    [CristmasVillage Driver 1-0.brd]
2014-12-22 Changed from FM tuned antenna idea to Zener Noise for random: v1.1
    [CristmasVillage Driver 1-1.brd, CristmasVillage Driver 1-1.sch]
2014-12-22 First attempt at light sensor code
2014-12-22 Sensor Chip software function complete (needs splitting into header files) - first creation of driver project
2014-12-22 Comments with pin configuration and temporary Set-All-LEDs-On code for DEMO
2014-12-22 Filling in the Watchdog Interrupt
2014-12-23 Removed a small mistake in getting EE-data to RAM
    [Driver_1-0.c]
2014-12-23 Got Random number generator working: small mistake
    [Driver_1-0.c]
2014-12-23 Added a dedicated startup delay, to "show all lights" a while for testing wiring
2014-12-23 Tried moving processing into main loop using flags, but could not seem to find why compiler optimized it to broken. (No optimisation: worked, optimisation, any level: nothing)
    [Driver_1-0.c]
2014-12-27 Start of building USART interface, designed command set, started implementing interrupts
2014-12-27 Added majority of usart commands, todo: bulk read and write of pattern data. USART now officially too large for 2313 types (TODO: Make USART optional)
    [Config.h, Driver.c]
2014-12-28 Merged in Github LICENSE, current version still untested (hardware temporarily unavailable)
2014-12-28 Fixed some mistakes and oversights in readme
    Added a bit more clarity to the process and fixed a couple of typos before it's finally bed time.
2014-12-28 Added opt. filter caps to hardware & created PDF exports of v1.2
    [CristmasVillage Driver 1-2.brd, CristmasVillage Driver 1-2.sch]
2014-12-28 Removed some USART bugs, 80% tested.
    [Config.h, Driver.c]
2014-12-28 Cleaned up silkscreen - added gerber exports
    [CristmasVillage Driver 1-2.brd, CristmasVillage Driver 1-3.brd, CristmasVillage Driver 1-3.sch]
2014-12-28 Added a partslist
    [Partlist.csv]
2014-12-29 Made some USART TX changes, stuff got broken somewhere
    [Config.h, Driver.c]
2014-12-31 Turned the USART into a half-duplex device. This avoids overwriting commands when the host PC doesn't wait for ACK/NACK messages. Larger/more expensive devices can use more complex buffering to allow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
    [Config.h, Driver.c]

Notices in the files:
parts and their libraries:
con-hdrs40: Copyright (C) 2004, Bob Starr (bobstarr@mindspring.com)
